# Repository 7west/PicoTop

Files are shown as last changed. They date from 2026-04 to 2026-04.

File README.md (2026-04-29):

# PicoTop

PicoTop is a small computer and operating system built around the RP2350. **This project is a work in progress.** It outputs a black and white terminal over HDMI and takes input from a USB keyboard. It runs its own keyboard-only OS with a shell, text editor, and a small set of programs. "PicoTop" is like laptop, except this one requires you to BYO monitor and keyboard... so not really a laptop at all. I came up with the name before a project pivot.

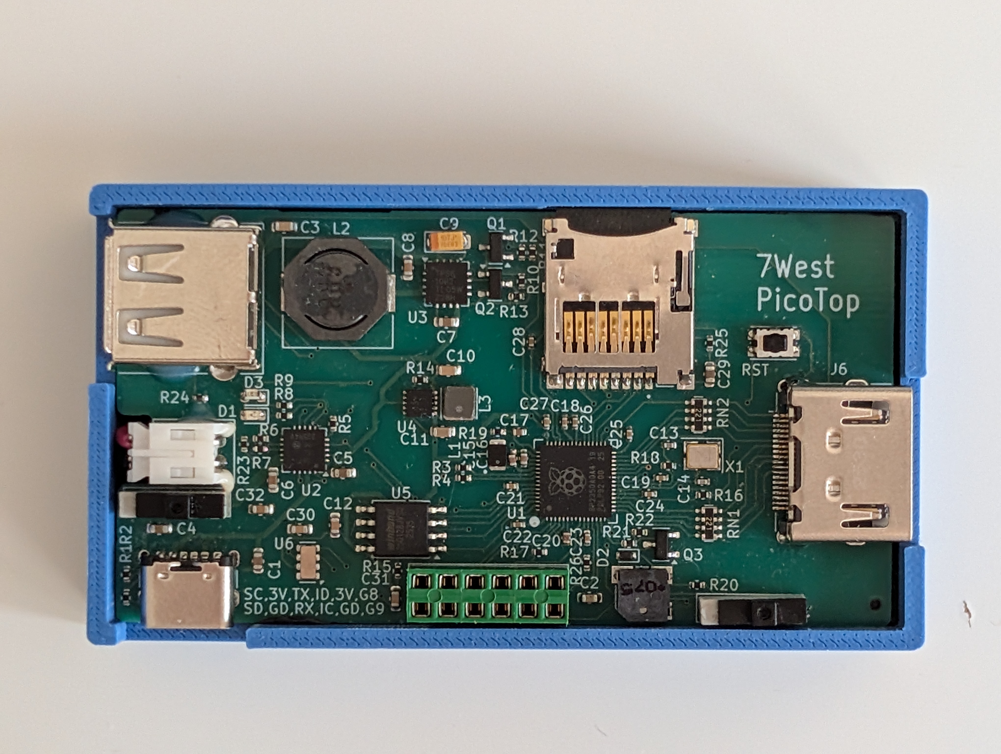
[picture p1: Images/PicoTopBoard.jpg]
PicoTop PCB


## Features

- **HDMI out** - 640x480 terminal display over DVI
- **USB keyboard** - standard USB-A keyboard input
- **Rechargeable** - onboard LiPo battery with USB-C charging; battery level visible in the top bar
- **SD card file system** - FAT16 on a micro SD card (FAT16 only; cards must be 2GB or smaller. I have only tested 2GB and 512MB)
- **RTC** - onboard real-time clock keeps time across power cycles
- **Exposed Pins** - 10 female headers expose 3V3, GND, I2C, UART, two GPIO pins, and SWD (to program the RP2350)
- **Vault** - A system to encrypt a 'vault' folder in the file system

## Programs

| Program | Description |
|---|---|
| `shell` | Command-line interface; entry point for all programs and commands |
| `uEdit` | Text editor |
| `calc` | Calculator workbook |
| `hangman` | Hangman game |
| `ptable` | Periodic Table of Elements reference |

### Shell Commands

`history`, `debug-log`, `timeset`, `battv`, `i2ct`, `beep`, `clear`, `ls`, `pwd`, `cd`, `mkdir`, `rmdir`, `rm`, `cp`, `mv`, `sd-format`, `sd-mount`, `sd-unmount`, and GPIO interaction commands. All commands have a `-h` option to describe what they do and how to use them.

## Repo Contents

- HARDWARE/ has the schematics and PCB for the computer and the case .stl files to 3D print the case.
- SOFTWARE/ has all the code. Open that with VS Code and the Pico SDK plugin and build/upload the "shellwork" project.

## Notes

This FAT16 file system does NOT support LFN (Long File Names). It strictly uses 8.3 naming; 8 characters for the file/folder name and 3 for the file/folder extension.

This repository is not used for active development, so everything is in one commit. It will be updated again at the next major milestone.

I am not great at coding, so you will probably find a lot of bad practices and bugs, but I am mostly happy with where the project is right now. I used AI to help write a few snippets and also help with the certain architectures, like for the file system and the text editor.

## More Images

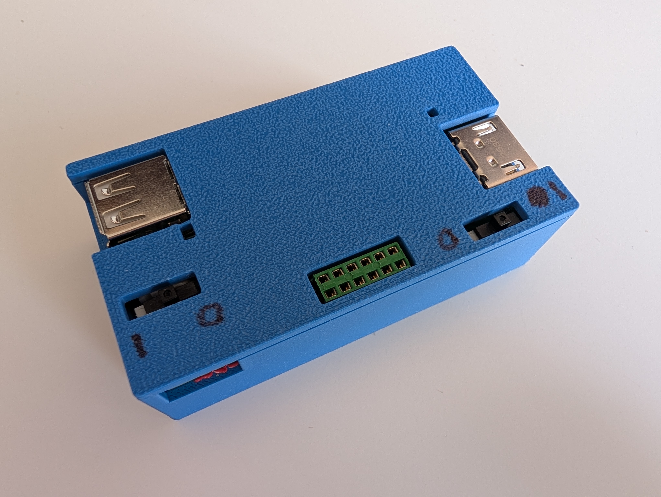
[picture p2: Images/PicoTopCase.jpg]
PicoTop in its 3D printed case


PicoTop in its 3D printed case

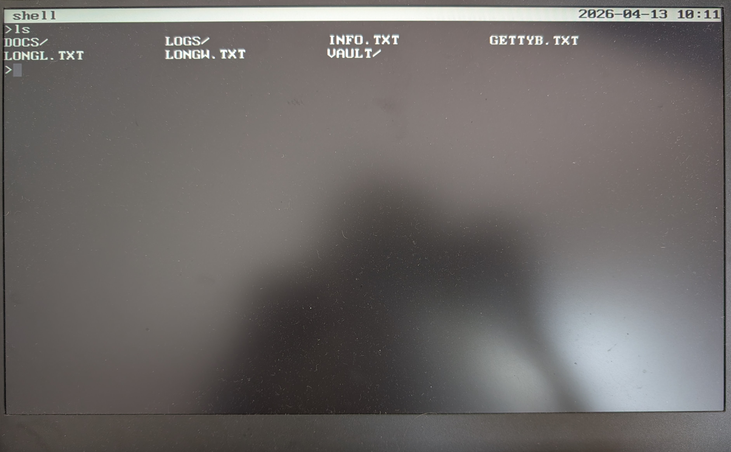
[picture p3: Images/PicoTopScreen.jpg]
Shell program showing a basic shell command


Shell program showing the `ls` command. You can see the VAULT/ folder and that all files and folders follow the 8.3 FAT16 naming convention.

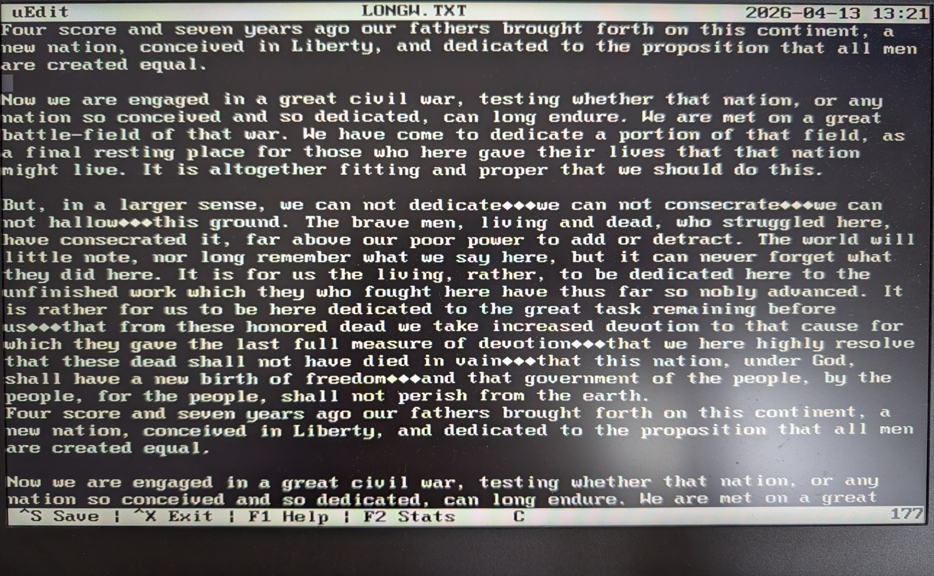
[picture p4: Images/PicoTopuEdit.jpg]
uEdit text editor


uEdit - The simple text editor.

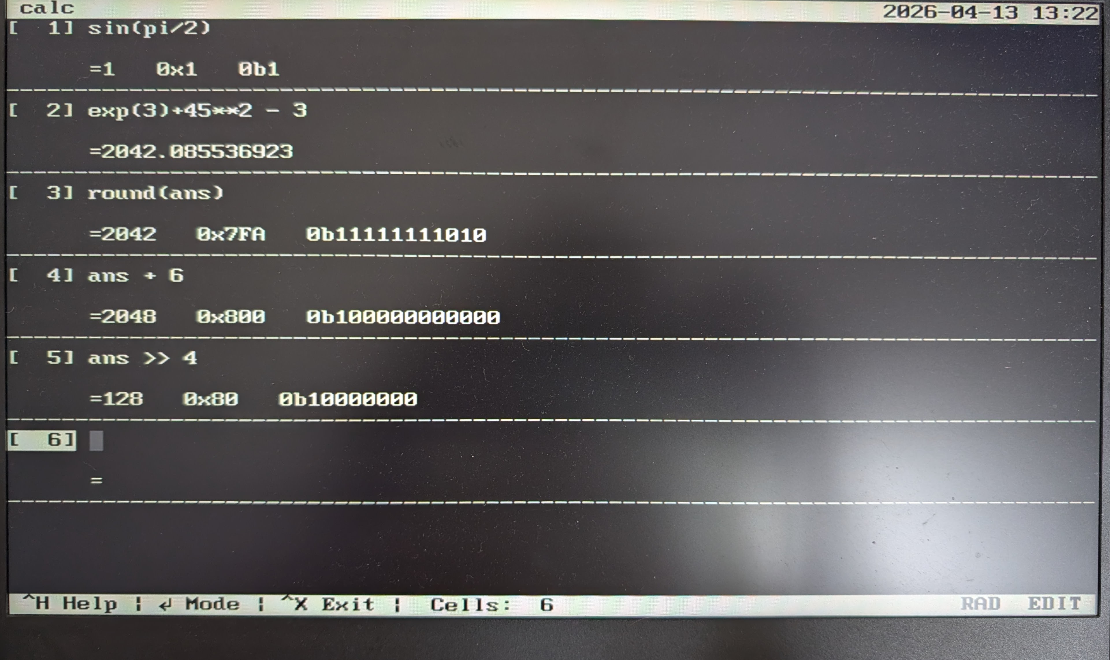
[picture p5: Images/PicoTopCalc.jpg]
calc, the calculator workbook program


calc - The simple calculator workbook program.

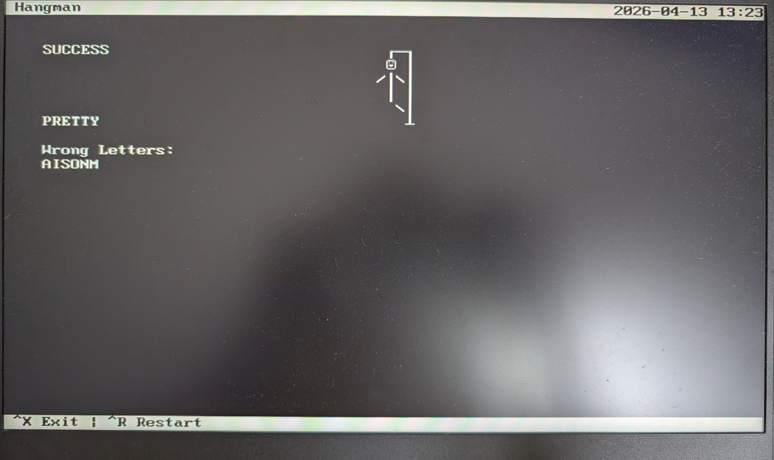
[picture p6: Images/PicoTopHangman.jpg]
Just a small hangman game


Hangman - so I can say yes to "does it have any games?"

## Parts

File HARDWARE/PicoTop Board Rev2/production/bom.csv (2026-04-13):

Designator | Footprint | Quantity | Value | LCSC Part #
C1, C29, C4 | 0603 | 3 | 10uF
C10, C11, C3 | 0603 | 3 | 47uF
C12, C2, C30, C31, C32 | 0603 | 5 | 0.1uF
C13, C14 | 0402 | 2 | 15pF
C15, C16, C17, C20 | 0402 | 4 | 4.7uF
C18, C19, C21, C22, C23, C24, C25, C26, C27, C28 | 0402 | 10 | 0.1uF
C5, C6, C7 | 0603 | 3 | 4.7uF
C8 | 0603 | 1 | 2.2uF
D2 | D_SOD-523 | 1 | 1N914BWT | 1N914BWT
L1 | 0805 | 1 | 3.3uH | AOTA-B201610S3R3-101-T
Q1 | SOT-23 | 1 | 2N7002 | 2N7002
Q2 | SOT-23 | 1 | BSS84 | BSS84
Q3 | SOT-23-3 | 1 | BC817 | BC817-25LT1G
R1, R2 | 0402 | 2 | 5.1k
R10, R12, R13, R22 | 0402 | 4 | 47k
R11, R18, R21 | 0402 | 3 | 1k
R14, R20, R6 | 0402 | 3 | 100k
R15, R16, R17, R25, R26, R5, R7 | 0402 | 7 | 10k
R19 | 0402 | 1 | 33
R23, R24 | 0402 | 2 | 1M
R3, R4 | 0402 | 2 | 27
R8, R9 | 0402 | 2 | 2.2k
RN1, RN2 | R_Array_Concave_4x0603 | 2 | 220
U1 | RP2350A_QFN-60_EP_7.75x7.75_Pitch0.4mm | 1 | RP2350A-QFN60 | SC1509-A4
U2 | QFN-20-1EP_4x4mm_P0.5mm_EP2.5x2.5mm | 1 | MCP73871-2CCI/ML | MCP73871-2CCI/ML
U3 | Texas_RSA_VQFN-16-1EP_4x4mm_P0.65mm_EP2.7x2.7mm_ThermalVias | 1 | TPS61092RSAR | TPS61092RSAR
U5 | SOIC-8_5.3x5.3mm_P1.27mm | 1 | W25Q128JVS
U6 | MicroCrystal_C7_SON-8_1.5x3.2mm_P0.9mm | 1 | RV-3028-C7
X1 | Crystal_SMD_Abracon_ABM8AIG-4Pin_3.2x2.5mm | 1 | ABM8-272-T3 | ABM8-272-T3

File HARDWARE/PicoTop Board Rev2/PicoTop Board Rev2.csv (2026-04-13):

Reference | Qty | Value | DNP | Exclude from BOM | Exclude from Board | Footprint | PACKAGE | MPN
5V1 | 1 | TestPoint | DNP | Excluded from BOM |  | TestPoint:TestPoint_THTPad_D1.5mm_Drill0.7mm
C1 | 1 | 0.1uF |  |  |  | Capacitor_SMD:C_0603_1608Metric | 0603
C3 | 1 | 47uF |  |  |  | Capacitor_SMD:C_0603_1608Metric | 0603
C4 | 1 | 10uF |  |  |  | Capacitor_SMD:C_0603_1608Metric | 0603
C5 | 1 | 4.7uF |  |  |  | Capacitor_SMD:C_0603_1608Metric | 0603
C6 | 1 | 4.7uF |  |  |  | Capacitor_SMD:C_0603_1608Metric | 0603
C7 | 1 | 4.7uF |  |  |  | Capacitor_SMD:C_0603_1608Metric | 0603
C8 | 1 | 2.2uF |  |  |  | Capacitor_SMD:C_0603_1608Metric | 0603
C9 | 1 | 100uF |  |  |  | Capacitor_Tantalum_SMD:CP_EIA-2012-15_AVX-P | 0805
C10 | 1 | 47uF |  |  |  | Capacitor_SMD:C_0603_1608Metric | 0603
C11 | 1 | 47uF |  |  |  | Capacitor_SMD:C_0603_1608Metric | 0603
C12 | 1 | 0.1uF |  |  |  | Capacitor_SMD:C_0603_1608Metric | 0603
C13 | 1 | 15pF |  |  |  | Capacitor_SMD:C_0402_1005Metric | 0402
C14 | 1 | 15pF |  |  |  | Capacitor_SMD:C_0402_1005Metric | 0402
C15 | 1 | 4.7uF |  |  |  | Capacitor_SMD:C_0402_1005Metric | 0402
C16 | 1 | 4.7uF |  |  |  | Capacitor_SMD:C_0402_1005Metric | 0402
C17 | 1 | 4.7uF |  |  |  | Capacitor_SMD:C_0402_1005Metric | 0402
C18 | 1 | 0.1uF |  |  |  | Capacitor_SMD:C_0402_1005Metric | 0402
C19 | 1 | 0.1uF |  |  |  | Capacitor_SMD:C_0402_1005Metric | 0402
C20 | 1 | 4.7uF |  |  |  | Capacitor_SMD:C_0402_1005Metric | 0402
C21 | 1 | 0.1uF |  |  |  | Capacitor_SMD:C_0402_1005Metric | 0402
C22 | 1 | 0.1uF |  |  |  | Capacitor_SMD:C_0402_1005Metric | 0402
C23 | 1 | 0.1uF |  |  |  | Capacitor_SMD:C_0402_1005Metric | 0402
C24 | 1 | 0.1uF |  |  |  | Capacitor_SMD:C_0402_1005Metric | 0402
C25 | 1 | 0.1uF |  |  |  | Capacitor_SMD:C_0402_1005Metric | 0402
C26 | 1 | 0.1uF |  |  |  | Capacitor_SMD:C_0402_1005Metric | 0402
C27 | 1 | 0.1uF |  |  |  | Capacitor_SMD:C_0402_1005Metric | 0402
C28 | 1 | 0.1uF |  |  |  | Capacitor_SMD:C_0402_1005Metric | 0402
C29 | 1 | 0.1uF |  |  |  | Capacitor_SMD:C_0603_1608Metric | 0603
C31 | 1 | 0.1uF |  |  |  | Capacitor_SMD:C_0603_1608Metric | 0603
D1 | 1 | LED |  |  |  | LED_SMD:LED_0603_1608Metric |  | LTST-C190KFKT
D2 | 1 | 1N914BWT |  |  |  | Diode_SMD:D_SOD-523 |  | 1N914BWT
D3 | 1 | LED |  |  |  | LED_SMD:LED_0603_1608Metric |  | LTST-S270KGKT
GND1 | 1 | TestPoint | DNP | Excluded from BOM |  | TestPoint:TestPoint_THTPad_D1.5mm_Drill0.7mm
GND2 | 1 | TestPoint | DNP | Excluded from BOM |  | TestPoint:TestPoint_Pad_3.0x3.0mm
J1 | 1 | Conn_02x06_Odd_Even | DNP | Excluded from BOM |  | Connector_PinHeader_2.54mm:PinHeader_2x06_P2.54mm_Vertical
J2 | 1 | USB_C_Receptacle_PowerOnly_6P | DNP | Excluded from BOM |  | Connector_USB:USB_C_Receptacle_GCT_USB4125-xx-x-0190_6P_TopMnt_Horizontal
J3 | 1 | MSD-7-A | DNP | Excluded from BOM |  | MSD_7_A:CUI_MSD-7-A
J4 | 1 | USB-A1HSW6 | DNP | Excluded from BOM |  | USB_A1HSW6:OST_USB-A1HSW6
J5 | 1 | S2B-PH-K-SLFSN | DNP | Excluded from BOM |  | footprints:CONN_S2B-PH-K-S_JST
L1 | 1 | 3.3uH |  |  |  | Inductor_SMD:L_0805_2012Metric |  | AOTA-B201610S3R3-101-T
L2 | 1 | 6.8uH |  |  |  | Inductor_SMD:L_10.4x10.4_H4.8 |  | SRU1028-6R8Y
L3 | 1 | 2.2uH |  |  |  | Inductor_SMD:L_Coilcraft_LPS3010 |  | VLS3012HBX-2R2M
LS1 | 1 | CSS-0578-SMT | DNP | Excluded from BOM |  | CSS_0578_SMT_TR:CUI_CSS-0578-SMT | None
Q1 | 1 | 2N7002 |  |  |  | Package_TO_SOT_SMD:SOT-23 |  | 2N7002
Q2 | 1 | BSS84 |  |  |  | Package_TO_SOT_SMD:SOT-23 |  | BSS84
Q3 | 1 | BC817 |  |  |  | Package_TO_SOT_SMD:SOT-23-3 |  | BC817-25LT1G
R1 | 1 | 5.1k |  |  |  | Resistor_SMD:R_0402_1005Metric | 0402
R2 | 1 | 5.1k |  |  |  | Resistor_SMD:R_0402_1005Metric | 0402
R3 | 1 | 27 |  |  |  | Resistor_SMD:R_0402_1005Metric | 0402
R4 | 1 | 27 |  |  |  | Resistor_SMD:R_0402_1005Metric | 0402
R5 | 1 | 10k |  |  |  | Resistor_SMD:R_0402_1005Metric | 0402
R6 | 1 | 100k |  |  |  | Resistor_SMD:R_0402_1005Metric | 0402
R7 | 1 | 10k |  |  |  | Resistor_SMD:R_0402_1005Metric | 0402
R8 | 1 | 2.2k |  |  |  | Resistor_SMD:R_0402_1005Metric | 0402
R9 | 1 | 2.2k |  |  |  | Resistor_SMD:R_0402_1005Metric | 0402
R10 | 1 | 47k |  |  |  | Resistor_SMD:R_0402_1005Metric | 0402
R11 | 1 | 1k |  |  |  | Resistor_SMD:R_0402_1005Metric | 0402
R12 | 1 | 47k |  |  |  | Resistor_SMD:R_0402_1005Metric | 0402
R13 | 1 | 47k |  |  |  | Resistor_SMD:R_0402_1005Metric | 0402
R14 | 1 | 100k |  |  |  | Resistor_SMD:R_0402_1005Metric | 0402
R15 | 1 | 10k |  |  |  | Resistor_SMD:R_0402_1005Metric | 0402
R16 | 1 | 10k |  |  |  | Resistor_SMD:R_0402_1005Metric | 0402
R18 | 1 | 1k |  |  |  | Resistor_SMD:R_0402_1005Metric | 0402
R19 | 1 | 33 |  |  |  | Resistor_SMD:R_0402_1005Metric | 0402
R20 | 1 | 100k |  |  |  | Resistor_SMD:R_0402_1005Metric | 0402
R21 | 1 | 1k |  |  |  | Resistor_SMD:R_0402_1005Metric | 0402
R22 | 1 | 47k |  |  |  | Resistor_SMD:R_0402_1005Metric | 0402
R23 | 1 | 1M |  |  |  | Resistor_SMD:R_0402_1005Metric | 0402
R24 | 1 | 1M |  |  |  | Resistor_SMD:R_0402_1005Metric | 0402
R25 | 1 | 10k |  |  |  | Resistor_SMD:R_0402_1005Metric | 0402
RN1 | 1 | 220 |  |  |  | Resistor_SMD:R_Array_Concave_4x0603 | 4x0603
RN2 | 1 | 220 |  |  |  | Resistor_SMD:R_Array_Concave_4x0603 | 4x0603
SW1 | 1 | 09.03290.01 | DNP | Excluded from BOM |  | 09.03290.01-footprints:09.03290_EAO
SW2 | 1 | 09.03290.01 | DNP | Excluded from BOM |  | 09.03290.01-footprints:09.03290_EAO
SW4 | 1 | SW_MEC_5E | DNP | Excluded from BOM |  | 7west:7SW_Push_1P1T_NO_CK_KMR2
TX0G1 | 1 | TestPoint | DNP | Excluded from BOM |  | TestPoint:TestPoint_THTPad_D1.5mm_Drill0.7mm
TX0M1 | 1 | TestPoint | DNP | Excluded from BOM |  | TestPoint:TestPoint_THTPad_D1.5mm_Drill0.7mm
TX0P1 | 1 | TestPoint | DNP | Excluded from BOM |  | TestPoint:TestPoint_THTPad_D1.5mm_Drill0.7mm
TX1G1 | 1 | TestPoint | DNP | Excluded from BOM |  | TestPoint:TestPoint_THTPad_D1.5mm_Drill0.7mm
TX1M1 | 1 | TestPoint | DNP | Excluded from BOM |  | TestPoint:TestPoint_THTPad_D1.5mm_Drill0.7mm
TX1P1 | 1 | TestPoint | DNP | Excluded from BOM |  | TestPoint:TestPoint_THTPad_D1.5mm_Drill0.7mm
TX2G1 | 1 | TestPoint | DNP | Excluded from BOM |  | TestPoint:TestPoint_THTPad_D1.5mm_Drill0.7mm
TX2M1 | 1 | TestPoint | DNP | Excluded from BOM |  | TestPoint:TestPoint_THTPad_D1.5mm_Drill0.7mm
TX2P1 | 1 | TestPoint | DNP | Excluded from BOM |  | TestPoint:TestPoint_THTPad_D1.5mm_Drill0.7mm
TXCG1 | 1 | TestPoint | DNP | Excluded from BOM |  | TestPoint:TestPoint_THTPad_D1.5mm_Drill0.7mm
TXCM1 | 1 | TestPoint | DNP | Excluded from BOM |  | TestPoint:TestPoint_THTPad_D1.5mm_Drill0.7mm
TXCP1 | 1 | TestPoint | DNP | Excluded from BOM |  | TestPoint:TestPoint_THTPad_D1.5mm_Drill0.7mm
U1 | 1 | RP2350A-QFN60 |  |  |  | RP2350:RP2350A_QFN-60_EP_7.75x7.75_Pitch0.4mm |  | SC1509-A4
U2 | 1 | MCP73871-2CCI |  |  |  | Package_DFN_QFN:QFN-20-1EP_4x4mm_P0.5mm_EP2.5x2.5mm |  | MCP73871-2CCI/ML
U3 | 1 | TPS61092RSA |  |  |  | Package_DFN_QFN:Texas_RSA_VQFN-16-1EP_4x4mm_P0.65mm_EP2.7x2.7mm_ThermalVias |  | TPS61092RSAR
U4 | 1 | RT6150B-33GQW |  |  |  | RT6150B_33GQW:SON50P250X250X80-11N |  | RT6150B-33GQW
U5 | 1 | W25Q128JVS | DNP | Excluded from BOM |  | Package_SO:SOIC-8_5.3x5.3mm_P1.27mm
X1 | 1 | ABM8-272-T3 |  |  |  | Crystal:Crystal_SMD_Abracon_ABM8AIG-4Pin_3.2x2.5mm |  | ABM8-272-T3

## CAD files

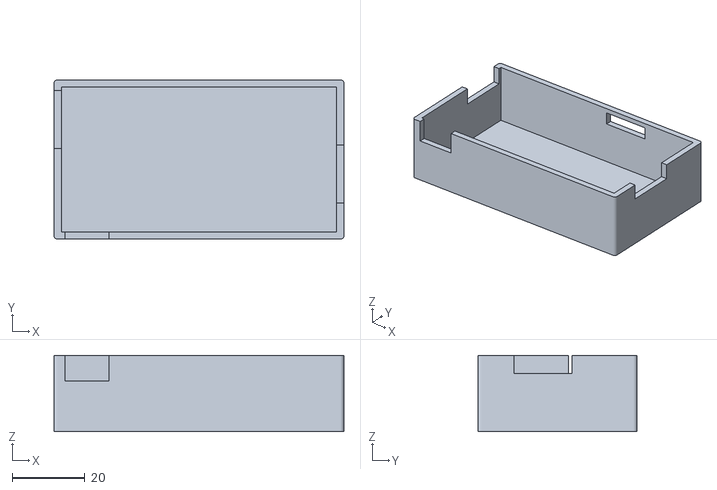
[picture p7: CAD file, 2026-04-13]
HARDWARE/3D Printed Case/Bottom_Rev5.stl
80.0 x 44.0 x 21.0

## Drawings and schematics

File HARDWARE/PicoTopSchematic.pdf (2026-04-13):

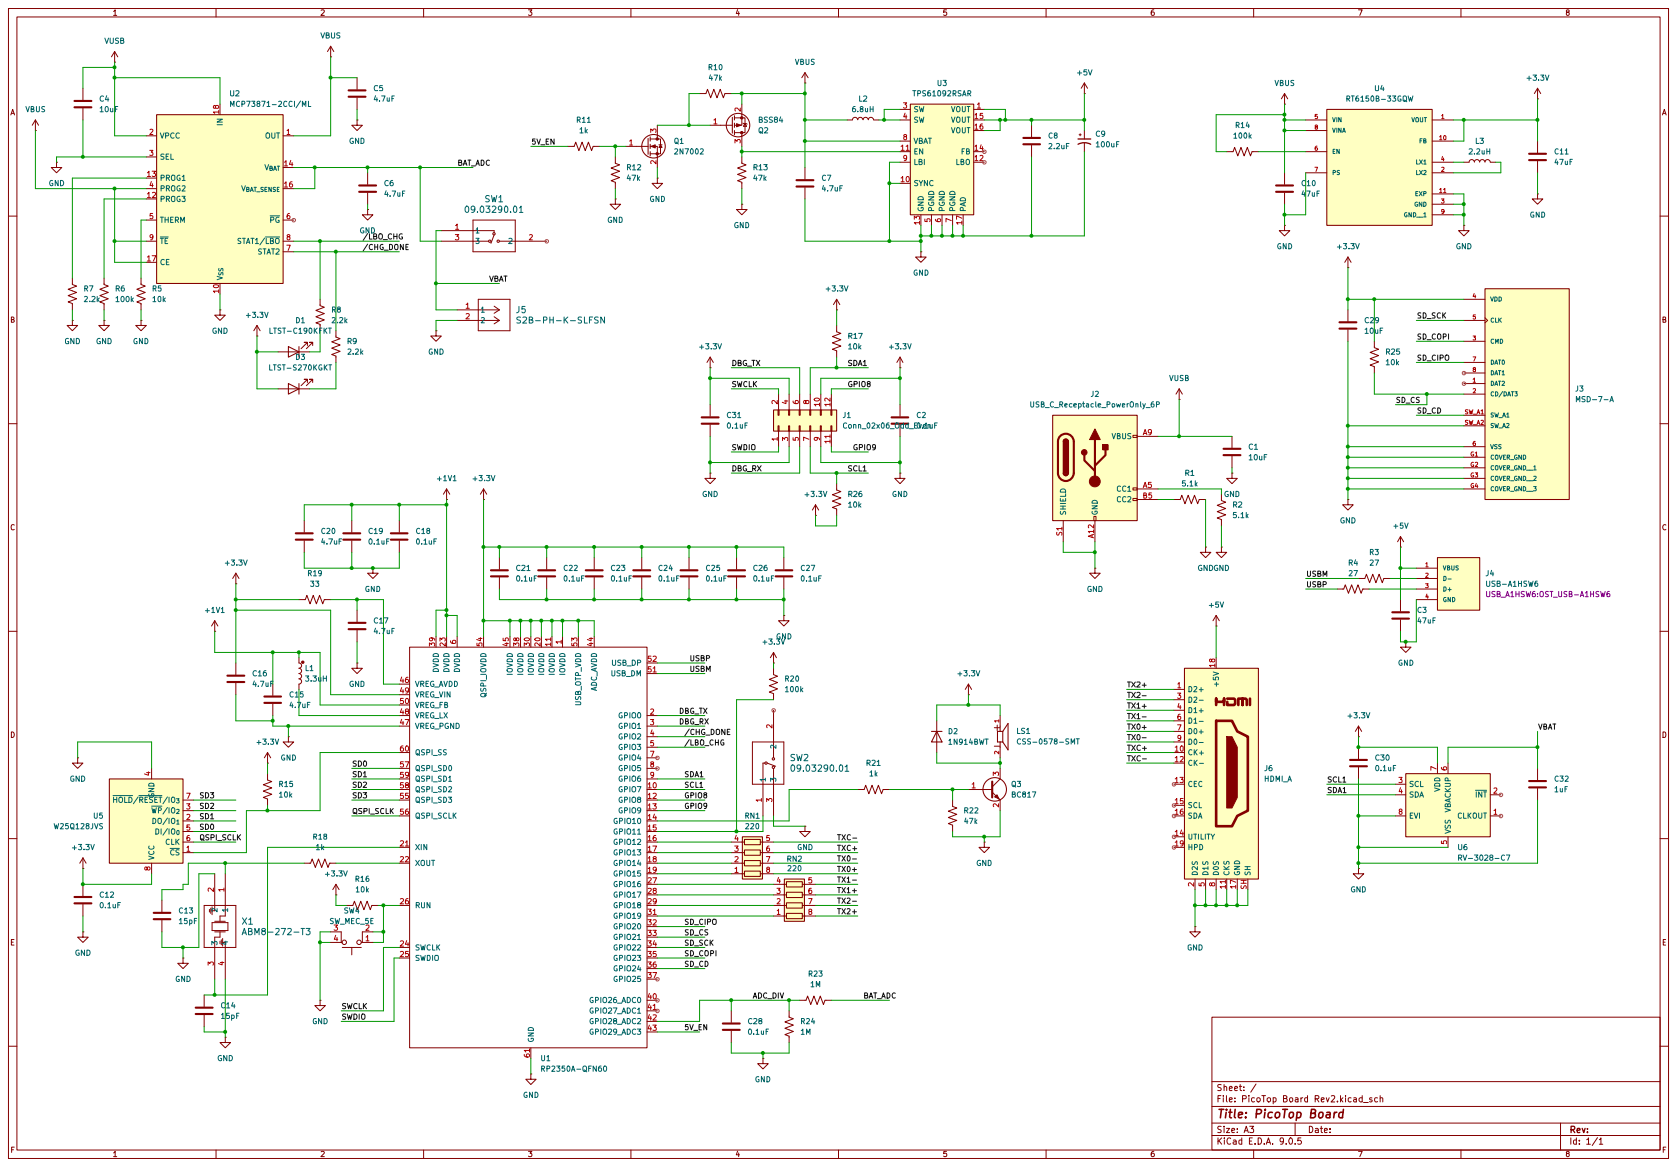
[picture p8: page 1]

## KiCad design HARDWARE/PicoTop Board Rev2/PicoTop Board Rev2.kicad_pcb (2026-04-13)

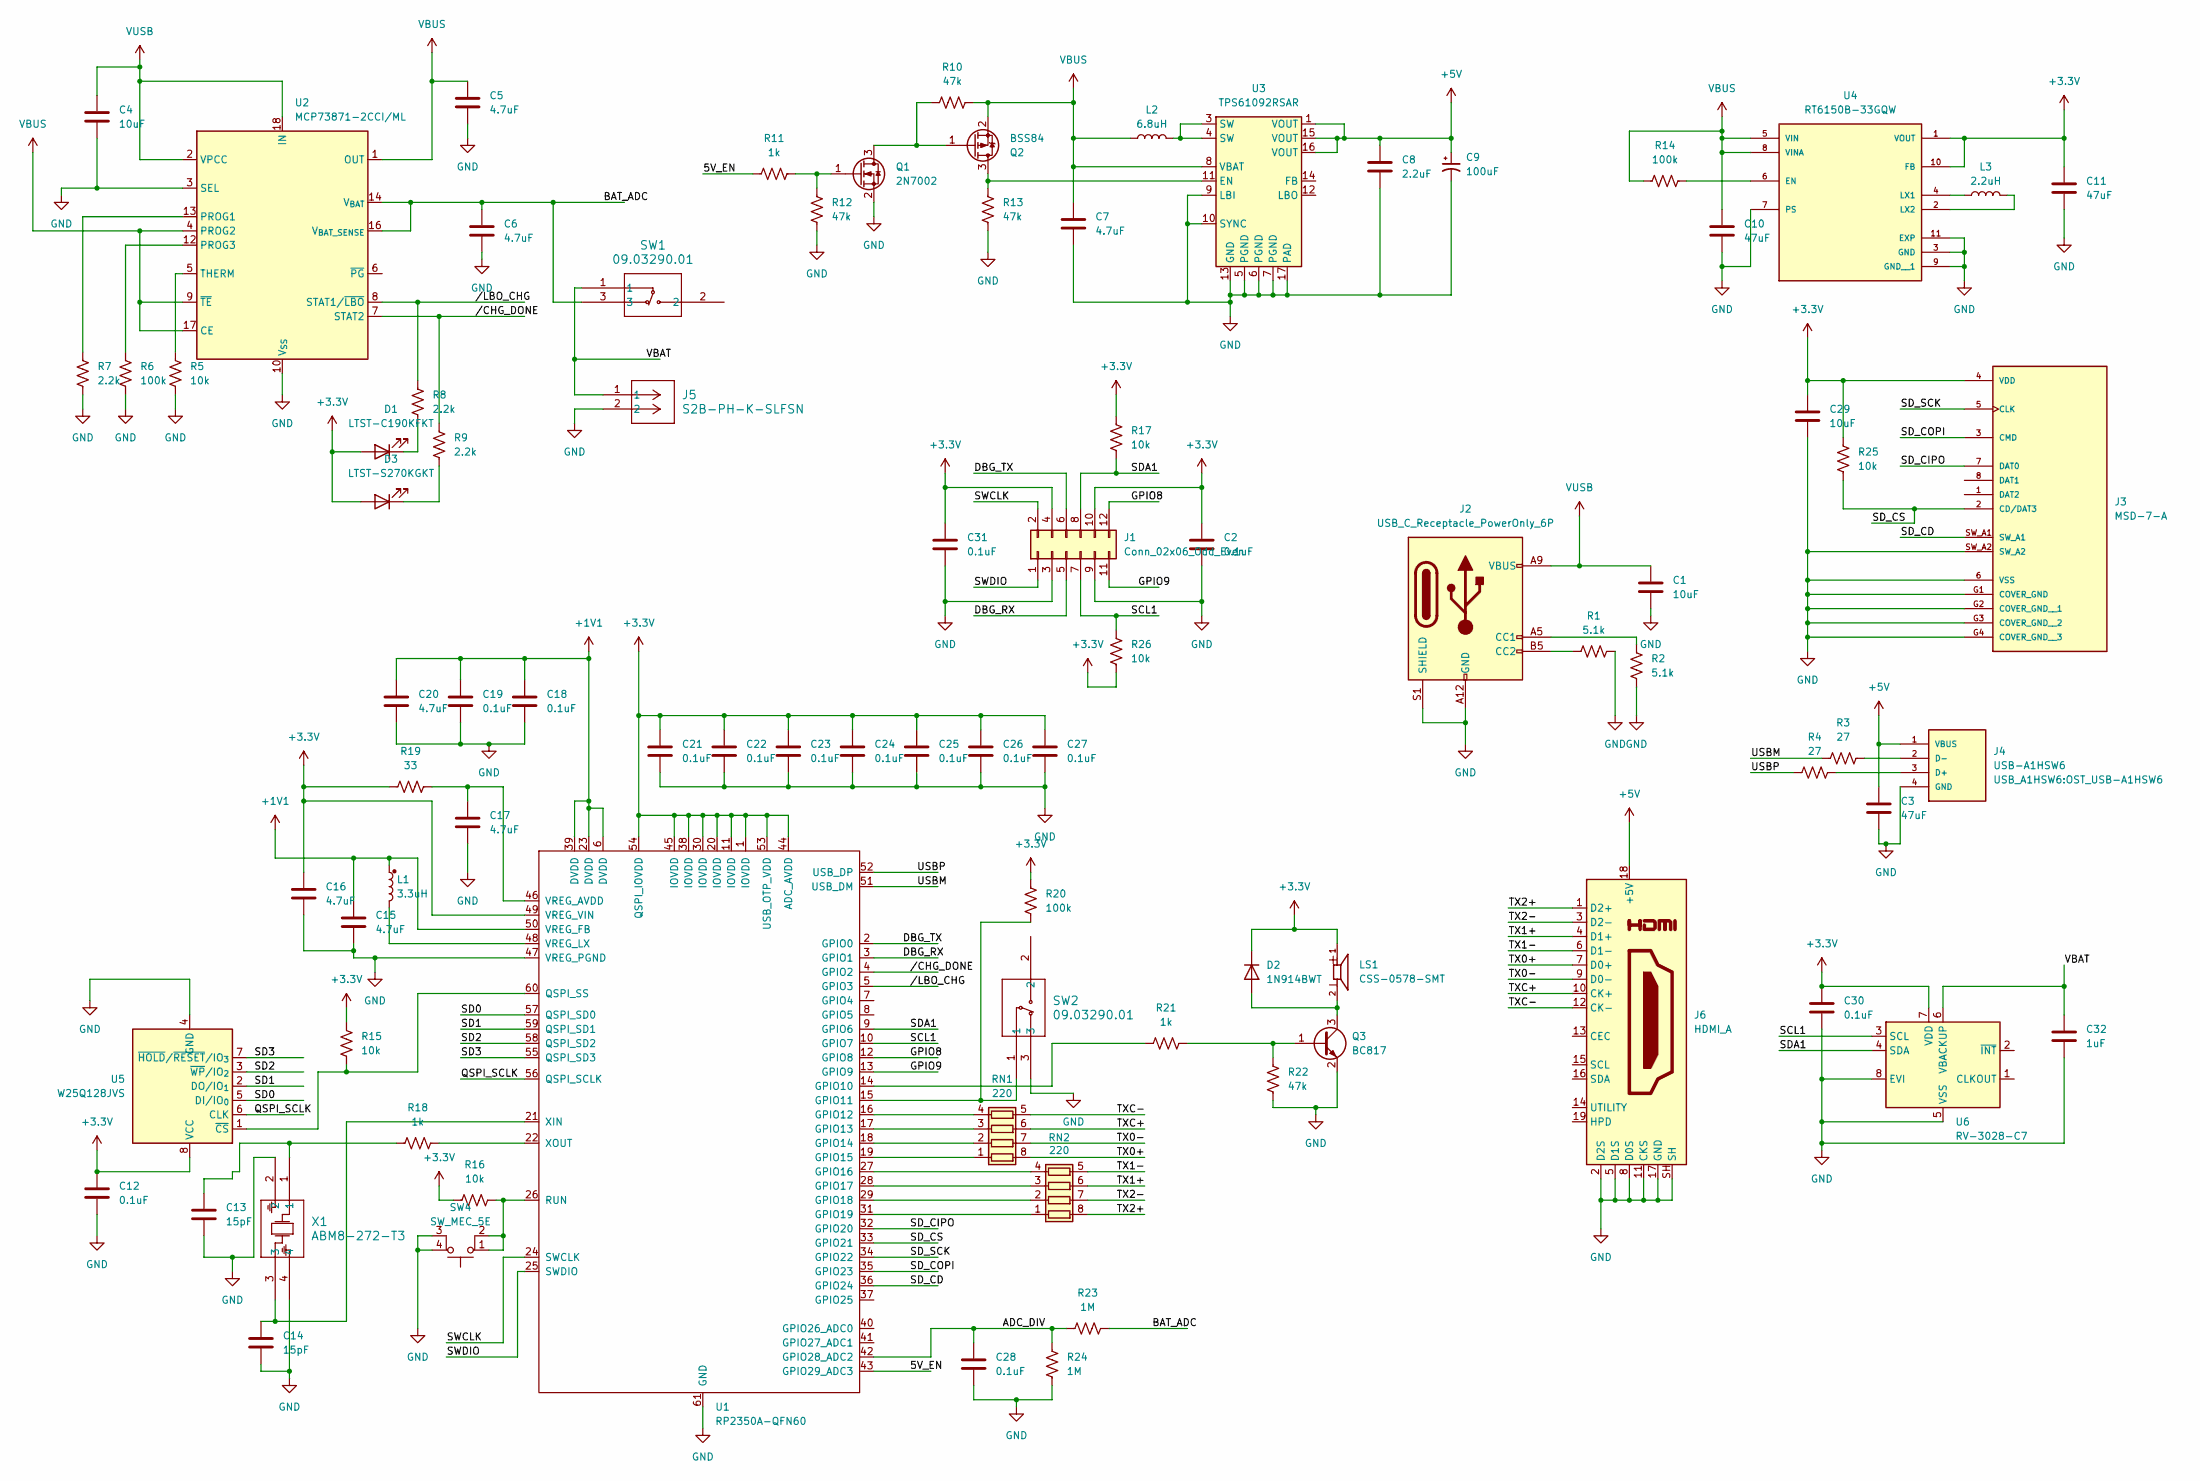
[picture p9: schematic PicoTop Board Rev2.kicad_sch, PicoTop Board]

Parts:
C1, C4, C29: 10uF; C_0603_1608Metric
C2, C12, C30, C31: 0.1uF; C_0603_1608Metric
C3, C10, C11: 47uF; C_0603_1608Metric
C5, C6, C7: 4.7uF; C_0603_1608Metric
C8: 2.2uF; C_0603_1608Metric
C9: 100uF; CP_EIA-3216-10_Kemet-I
C13, C14: 15pF; C_0402_1005Metric
C15, C16, C17, C20: 4.7uF; C_0402_1005Metric
C18, C19, C21, C22, C23, C24, C25, C26, C27, C28: 0.1uF; C_0402_1005Metric
C32: 1uF; C_0603_1608Metric
D1: LTST-C190KFKT; LED_0603_1608Metric; MPN LTST-C190KFKT
D2: 1N914BWT; D_SOD-523; MPN 1N914BWT
D3: LTST-S270KGKT; LED_0603_1608Metric; MPN LTST-S270KGKT
J1: Conn_02x06_Odd_Even; PinHeader_2x06_P2.54mm_Vertical
J2: USB_C_Receptacle_PowerOnly_6P; USB_C_Receptacle_GCT_USB4125-xx-x-0190_6P_TopMnt_Horizontal
J3: MSD-7-A; CUI_MSD-7-A; PARTREV 1.0
J4: USB-A1HSW6; OST_USB-A1HSW6; PARTREV A
J5: S2B-PH-K-SLFSN; CONN_S2B-PH-K-S_JST
J6: HDMI_A; HDMI_A_Molex_208658-1001_Horizontal
L1: 3.3uH; L_0805_2012Metric; MPN AOTA-B201610S3R3-101-T
L2: 6.8uH; L_10.4x10.4_H4.8; MPN SRU1028-6R8Y
L3: 2.2uH; L_Coilcraft_LPS3010; MPN VLS3012HBX-2R2M
LS1: CSS-0578-SMT; CUI_CSS-0578-SMT
Q1: 2N7002; SOT-23; MPN 2N7002
Q2: BSS84; SOT-23; MPN BSS84
Q3: BC817; SOT-23-3; MPN BC817-25LT1G
R1, R2: 5.1k; R_0402_1005Metric
R3, R4: 27; R_0402_1005Metric
R5, R15, R16, R17, R25, R26: 10k; R_0402_1005Metric
R6, R14, R20: 100k; R_0402_1005Metric
R7, R8, R9: 2.2k; R_0402_1005Metric
R10, R12, R13, R22: 47k; R_0402_1005Metric
R11, R18, R21: 1k; R_0402_1005Metric
R19: 33; R_0402_1005Metric
R23, R24: 1M; R_0402_1005Metric
RN1, RN2: 220; R_Array_Concave_4x0603
SW1, SW2: 09.03290.01; 09.03290_EAO
SW4: SW_MEC_5E; 7SW_Push_1P1T_NO_CK_KMR2
U1: RP2350A-QFN60; RP2350A_QFN-60_EP_7.75x7.75_Pitch0.4mm; MPN SC1509-A4
U2: MCP73871-2CCI/ML; QFN-20-1EP_4x4mm_P0.5mm_EP2.5x2.5mm; MPN MCP73871-2CCI/ML
U3: TPS61092RSAR; Texas_RSA_VQFN-16-1EP_4x4mm_P0.65mm_EP2.7x2.7mm_ThermalVias; MPN TPS61092RSAR
U4: RT6150B-33GQW; SON50P250X250X80-11N; PARTREV July 2018
U5: W25Q128JVS; SOIC-8_5.3x5.3mm_P1.27mm
U6: RV-3028-C7; MicroCrystal_C7_SON-8_1.5x3.2mm_P0.9mm
X1: ABM8-272-T3; Crystal_SMD_Abracon_ABM8AIG-4Pin_3.2x2.5mm; MPN ABM8-272-T3

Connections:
+1V1: C15.1, C18.1, C19.1, C20.1, L1.1 (PLUS), U1.6 (DVDD), U1.23 (DVDD), U1.39 (DVDD), U1.50 (VREG_FB)
+3.3V: C2.1, C11.1, C12.1, C16.1, C21.1, C22.1, C23.1, C24.1, C25.1, C26.1, C27.1, C29.1, C30.1, C31.1, D1.2 (A), D2.1 (K), D3.2 (A), J1.4, J1.10, J3.4 (VDD), LS1.1, R15.2, R16.2, R17.2, R19.2, R20.2, R25.2, R26.1, U1.1 (IOVDD), U1.11 (IOVDD), U1.20 (IOVDD), U1.30 (IOVDD), U1.38 (IOVDD), U1.44 (ADC_AVDD), U1.45 (IOVDD), U1.49 (VREG_VIN), U1.53 (USB_OTP_VDD), U1.54 (QSPI_IOVDD), U4.1 (VOUT), U4.10 (FB), U5.8 (VCC), U6.7 (VDD)
+5V: C3.2, C8.1, C9.1, J4.1 (VBUS), J6.18 (+5V), U3.1 (VOUT), U3.15 (VOUT), U3.16 (VOUT)
/5V_EN: R11.2, U1.43 (GPIO29_ADC3)
/ADC_DIV: C28.1, R23.2, R24.1, U1.42 (GPIO28_ADC2)
/BAT_ADC: C6.1, R23.1, SW1.3, U2.14 (V_{BAT}), U2.15 (V_{BAT}), U2.16 (V_{BAT_SENSE})
/DBG_RX: J1.5, U1.3 (GPIO1)
/DBG_TX: J1.6, U1.2 (GPIO0)
/GPIO8: J1.12, U1.12 (GPIO8)
/GPIO9: J1.11, U1.13 (GPIO9)
/QSPI_SCLK: U1.56 (QSPI_SCLK), U5.6 (CLK)
/SCL1: J1.7, R26.2, U1.10 (GPIO7), U6.3 (SCL)
/SD0: U1.57 (QSPI_SD0), U5.5 (DI/IO_{0})
/SD1: U1.59 (QSPI_SD1), U5.2 (DO/IO_{1})
/SD2: U1.58 (QSPI_SD2), U5.3 (~WP/IO_{2})
/SD3: U1.55 (QSPI_SD3), U5.7 (~HOLD/~RESET/IO_{3})
/SDA1: J1.8, R17.1, U1.9 (GPIO6), U6.4 (SDA)
/SD_CD: J3.SW_A1, U1.36 (GPIO24)
/SD_CIPO: J3.7 (DAT0), U1.32 (GPIO20)
/SD_COPI: J3.3 (CMD), U1.35 (GPIO23)
/SD_CS: J3.2 (CD/DAT3), R25.1, U1.33 (GPIO21)
/SD_SCK: J3.5 (CLK), U1.34 (GPIO22)
/SWCLK: J1.2, U1.24 (SWCLK)
/SWDIO: J1.1, U1.25 (SWDIO)
/TX0+: J6.7 (D0+), RN1.8 (R1.2)
/TX0-: J6.9 (D0-), RN1.7 (R2.2)
/TX1+: J6.4 (D1+), RN2.6 (R3.2)
/TX1-: J6.6 (D1-), RN2.5 (R4.2)
/TX2+: J6.1 (D2+), RN2.8 (R1.2)
/TX2-: J6.3 (D2-), RN2.7 (R2.2)
/TXC+: J6.10 (CK+), RN1.6 (R3.2)
/TXC-: J6.12 (CK-), RN1.5 (R4.2)
/USBM: R3.2, U1.51 (USB_DM)
/USBP: R4.2, U1.52 (USB_DP)
/VBAT: C32.1, J5.1, SW1.1, U6.6 (VBACKUP)
//CHG_DONE: R9.2, U1.4 (GPIO2), U2.7 (STAT2)
//LBO_CHG: R8.2, U1.5 (GPIO3), U2.8 (STAT1/~LBO)
GND: C1.2, C2.2, C3.1, C4.2, C5.2, C6.2, C7.2, C8.2, C9.2, C10.2, C11.2, C12.2, C13.2, C14.2, C15.2, C16.2, C17.2, C18.2, C19.2, C20.2, C21.2, C22.2, C23.2, C24.2, C25.2, C26.2, C27.2, C28.2, C29.2, C30.2, C31.2, C32.2, J1.3, J1.9, J2.A12 (GND), J2.B12 (GND), J2.S1 (SHIELD), J3.6 (VSS), J3.G1 (COVER_GND), J3.G2 (COVER_GND__1), J3.G3 (COVER_GND__2), J3.G4 (COVER_GND__3), J3.SW_A2, J4.4 (GND), J5.2, J6.2 (D2S), J6.5 (D1S), J6.8 (D0S), J6.11 (CKS), J6.17 (GND), J6.SH, Q1.2 (S), Q3.2 (E), R1.2, R2.1, R5.1, R6.1, R7.1, R12.2, R13.2, R22.2, R24.2, SW2.3, SW4.3 (K), SW4.4 (A), U1.47 (VREG_PGND), U1.61 (GND), U2.3 (SEL), U2.10 (V_{SS}), U2.11 (V_{SS}), U2.21 (V_{SS}), U3.5 (PGND), U3.6 (PGND), U3.7 (PGND), U3.9 (LBI), U3.10 (SYNC), U3.13 (GND), U3.17 (PAD), U4.3 (GND), U4.7 (PS), U4.9 (GND__1), U4.11 (EXP), U5.4 (GND), U6.5 (VSS), U6.8 (EVI), X1.2, X1.4
unnamed: C13.1, R18.2, X1.1
unnamed: D1.1 (K), R8.1
unnamed: D2.2 (A), LS1.2, Q3.3 (C)
unnamed: D3.1 (K), R9.1
unnamed: J2.A5 (CC1), R2.2
unnamed: J2.B5 (CC2), R1.1
unnamed: J4.3 (D+), R4.1
unnamed: J4.2 (D-), R3.1
unnamed: L1.2 (MINUS), U1.48 (VREG_LX)
unnamed: L2.2, U3.3 (SW), U3.4 (SW)
unnamed: Q1.3 (D), Q2.1 (G), R10.2
unnamed: Q1.1 (G), R11.1, R12.1
unnamed: Q2.3 (D), R13.1, U3.11 (EN)
unnamed: Q3.1 (B), R21.1, R22.1
unnamed: RN1.1 (R1.1), U1.19 (GPIO15)
unnamed: RN1.2 (R2.1), U1.18 (GPIO14)
unnamed: RN1.3 (R3.1), U1.17 (GPIO13)
unnamed: RN1.4 (R4.1), U1.16 (GPIO12)
unnamed: RN2.1 (R1.1), U1.31 (GPIO19)
unnamed: RN2.2 (R2.1), U1.29 (GPIO18)
unnamed: RN2.3 (R3.1), U1.28 (GPIO17)
unnamed: RN2.4 (R4.1), U1.27 (GPIO16)
unnamed: R21.2, U1.14 (GPIO10)
unnamed: R20.1, SW2.1, U1.15 (GPIO11)
unnamed: R15.1, U1.60 (QSPI_SS), U5.1 (~CS)
unnamed: R16.1, SW4.1, SW4.2, U1.26 (RUN)
unnamed: C17.1, R19.1, U1.46 (VREG_AVDD)
unnamed: C14.1, U1.21 (XIN), X1.3
unnamed: R18.1, U1.22 (XOUT)
unnamed: R7.2, U2.13 (PROG1)
unnamed: R6.2, U2.12 (PROG3)
unnamed: R5.2, U2.5 (THERM)
unnamed: R14.2, U4.6 (EN)
unnamed: L3.1, U4.4 (LX1)
unnamed: L3.2, U4.2 (LX2)
VBUS: C5.1, C7.1, C10.1, L2.1, Q2.2 (S), R10.1, R14.1, U2.1 (OUT), U2.4 (PROG2), U2.9 (~TE), U2.17 (CE), U2.20 (OUT), U3.8 (VBAT), U4.5 (VIN), U4.8 (VINA)
VUSB: C1.1, C4.1, J2.A9 (VBUS), J2.B9 (VBUS), U2.2 (VPCC), U2.18 (IN), U2.19 (IN)

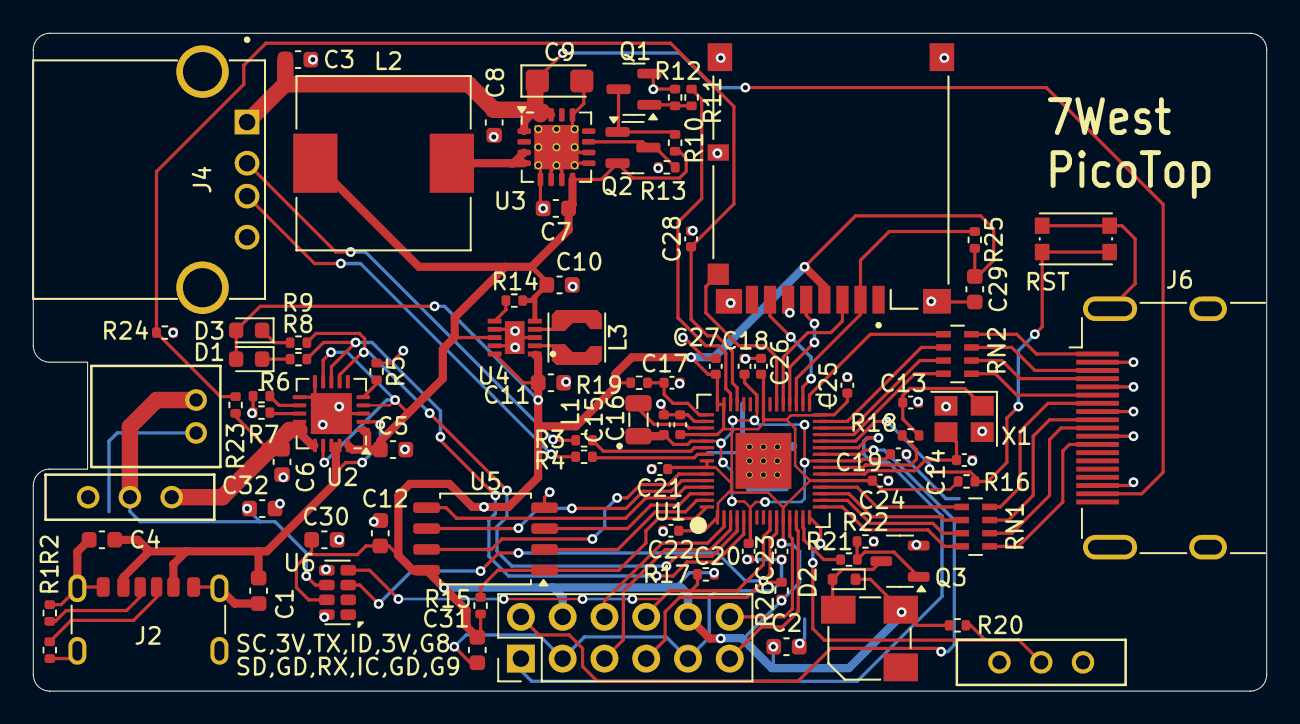
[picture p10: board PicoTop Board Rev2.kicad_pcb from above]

Board: 2 copper layers, 75.0 x 40.0 mm, 86 parts (0 on the bottom side), 75 nets.

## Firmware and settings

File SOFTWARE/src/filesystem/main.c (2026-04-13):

#include <stdio.h>
#include <string.h>

#include "pico/stdlib.h"
#include "pico/stdlib.h"
#include "hardware/gpio.h"
#include "pico/multicore.h"
#include "pico/sem.h"

#include "terminal.h"
#include "os_debug.h"
#include "sd_block.h"
#include "vfs.h"
#include "fat16.h"


static void core1_main(void) {

    term_init();

    // so DMA always overrules USB, otherwise DVI signal can choke and die
    irq_set_priority(DMA_IRQ_0, 0);
    irq_set_priority(USBCTRL_IRQ, 0xC0);

    while (1)
        __wfi();
}



uint8_t buffer[1472];


int main(void) {
    stdio_init_all();

    printf("START\n");

    multicore_launch_core1(core1_main);

    gpio_init(5);
    gpio_set_dir(5, GPIO_IN);
    gpio_pull_up(5);

    // sleep_ms(3000);

    term_clear_screen();

    term_set_cursor(0,29);
    term_puts("7West");
    term_set_cursor(0,0);


    if (vfs_init()) {
        printf("VFS Init Successful\n");
    } else {
        printf("VFS Init FAILED\n");
        debug_print_log_UART();
    }

    uint64_t time_pressed = time_us_64();


    while(true) {

        if (!gpio_get(5) && time_pressed + 500000 < time_us_64()) {
            time_pressed = time_us_64();

            if (vfs_exists("getty.txt")) {
                printf("file getty.txt exists\n");
            }
            if (vfs_exists("docs/novel")) {
                printf("dir /docs/novel/ exists");
            }
            if (vfs_exists("/logs/")) {
                printf("logs exists???????\n");
            }


        }

    }
}

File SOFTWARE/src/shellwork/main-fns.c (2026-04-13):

#include "includes.h"

static time_t last_min_epoch = 0;

#define INIT_USELESS_DELAY 100
#define LIGHTING_SYMBOL 174
#define PLUG_SYMBOL 175
#define GPIO_USER_8 8
#define GPIO_USER_9 9


void draw_batt_symbol(void) {

    if (batt_lbo_state()) {
        term_draw_char(62, 0, LIGHTING_SYMBOL);
    } else if (batt_chg_done_state()) {
        term_draw_char(62, 0, PLUG_SYMBOL);
    } else {
        term_draw_char(62, 0, 0); // blank
    }
    term_invert_cell(62, 0);
}

void init_os(void) {
    sleep_ms(2000);
    term_clear_screen();

    gpio_init(GPIO_USER_8);
    gpio_init(GPIO_USER_9);

    term_draw_string(1, 0, "7West");
    term_invert_line(0);
    sleep_ms(INIT_USELESS_DELAY); // this is stupid

    term_set_cursor(0,1);
    term_puts("Starting up WestOS...");
    term_new_line();
    sleep_ms(INIT_USELESS_DELAY); // this is stupid

    batt_init_monitor();

    term_puts("Starting up RTC... ");
    sleep_ms(INIT_USELESS_DELAY); // this is stupid
    if (rtc_init()) {
        term_puts("Success");
    } else {
        debug_deposit("RTCL-WARN-RTC failed to start up at OS startup", 0, DBG_NULL_VAR);
        term_puts("Fail");
    }
    // get initial time for periodic minute check
    // rtc_get_time(&now);
    // last_min = now.tm_min;
    // next_check_us = time_us_64() + ((59ULL - now.tm_sec) * 1000000ULL);

    update_ui_time();
    term_new_line();
    sleep_ms(INIT_USELESS_DELAY); // this is stupid

    term_puts("Mounting FAT16 & virtual file system... ");
    sleep_ms(INIT_USELESS_DELAY); // this is stupid
    if (vfs_init()) {
        term_puts("Success");
        vault_update_status();
    } else {
        debug_deposit("VFSL-WARN-Virtual File System failed to start up at OS startup", 0, DBG_NULL_VAR);
        term_puts("Fail");
    }
    term_new_line();
    sleep_ms(INIT_USELESS_DELAY); // this is stupid

    term_puts("Detecting keyboard... ");
    sleep_ms(INIT_USELESS_DELAY); // this is stupid

    uint64_t start_time = time_us_64();
    bool not_timeout = true;
    while (not_timeout && !keyboard_is_up()) {
        not_timeout = time_us_64() - start_time < 2000000;
    }
    if (not_timeout) {
        term_puts("Success");
    } else {
        debug_deposit("USBK-WARN-USB Keyboard failed to be detected. Replug in?", 0, DBG_NULL_VAR);
        term_puts("Fail");
    }
    term_new_line();
    sleep_ms(INIT_USELESS_DELAY); // this is stupid

    term_new_line();
    term_puts("OS Loaded");
    // buzz_play_library(5); // TODO: disabled for now because I reboot A LOT
    sleep_ms(1000); // not stupid

    prog_switch(&shell_prog);
    draw_ui_bar();

}

// for functions needed every minute
void check_periodic_min(void) {
    
    struct timespec ts;    
    rtc_get_epoch(&ts);

    if ((ts.tv_sec / 60) != last_min_epoch) {
        // === Stuff that runs every minute:

        update_ui_time();

        draw_batt_symbol();

        // debug_file_periodic();






        last_min_epoch = ts.tv_sec / 60;
    }
}

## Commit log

2026-04-13 Reorganized and added hardware files
    Added KiCAD project files and 3D printing files. Reorganized repo into
    hardware & software folders
    [Bottom_Rev5.stl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]
2026-04-29 Fixed several bugs and added new features
    Fixed uEdit bugs (scrolling near the end of files). Added calc features
    (complex numbers, numerical solving, derivatives, and integration).
    Added new periodic table program (ptable). Added new I2C tool (i2ct).
